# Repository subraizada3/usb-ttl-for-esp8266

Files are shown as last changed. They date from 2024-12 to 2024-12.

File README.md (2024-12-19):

# USB UART TTL for ESP8266

This is a compact CP2102N-based USB Type-C TTL UART breakout board that also includes the DTR and RTS pins needed for button-free programming of the ESP8266.

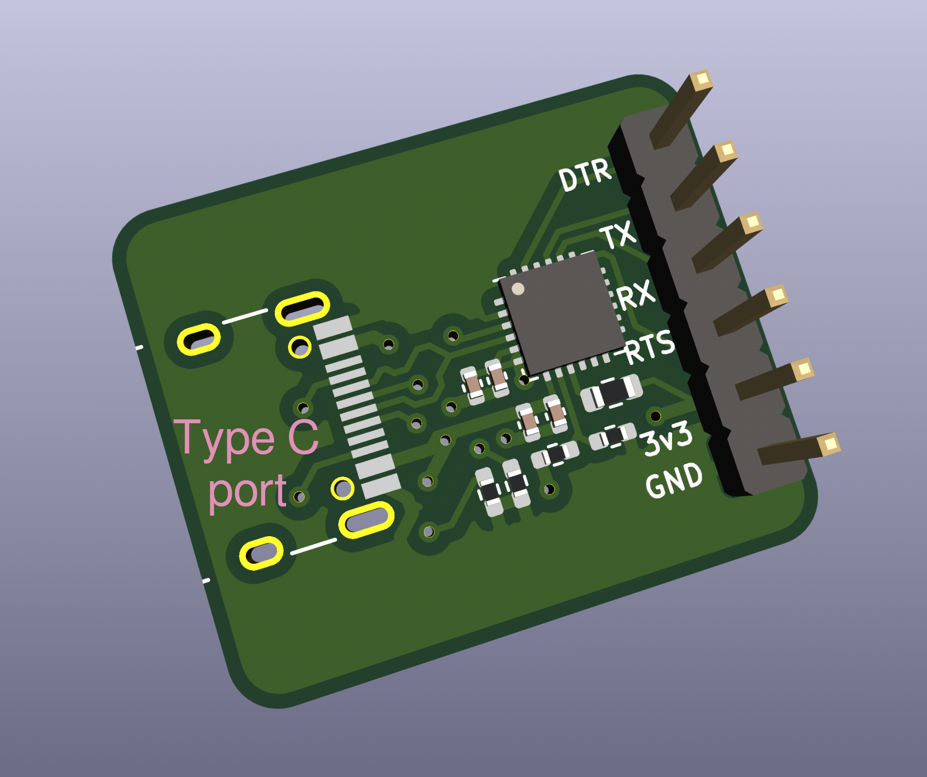
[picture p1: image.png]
image of board


USB TTL UART adapters available on the market have issues:
- The smaller adapters that have a Type C port don't break out the DTR & RTS pins
- The adapters that do break out DTR & RTS pins also break out a bunch of other unneeded pins, and they're large & bulky. They also have a micro-USB port instead of Type C.

This adapter breaks out all pins needed for efficient ESP8266 development while remaining as compact as possible.

This was created in 2021; the market may have more suitable offerings available at this point.

See [bom.xlsx](bom.xlsx) for the list of parts to order from LCSC or for JLCPCB assembly. [pos.xlsx](pos.xlsx) is the part positioning file for JLCPCB assembly.

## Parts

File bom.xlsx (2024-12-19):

Comment | Qty | Designator | Footprint | Name | LCSC Part # | Extended?
CP2102N 24 pin | 1 | U1 | QFN-24_4x4x05P | CP2102N-A02-GQFN24R | C969151 | Yes
USB type C 12 pin | 1 | J1 | TYPE-C-31_L8.94_W7.3 | TYPE-C-31-M-12 | C165948 | Yes
Male header 1x6 | 1 | J2 | Through hole | C37208 | C37208
Resistor 5.1k | 2 | R1,R2 | R0402 | 0402WGF5101TCE | C25905
Resistor 1k | 1 | R3 | R0603 | 0603WAF1001T5E | C21190
Resistor 22k | 1 | R4 | R0402 | 0402WGF2202TCE | C25768
Resistor 47k | 1 | R5 | R0402 | 0402WGF4702TCE | C25792
Capacitor 4.7uF | 2 | C1,C3 | C0402 | CL05A475MP5NRNC | C23733
Capacitor 100nF | 2 | C2,C4 | C0402 | CL05B104KO5NNNC | C1525

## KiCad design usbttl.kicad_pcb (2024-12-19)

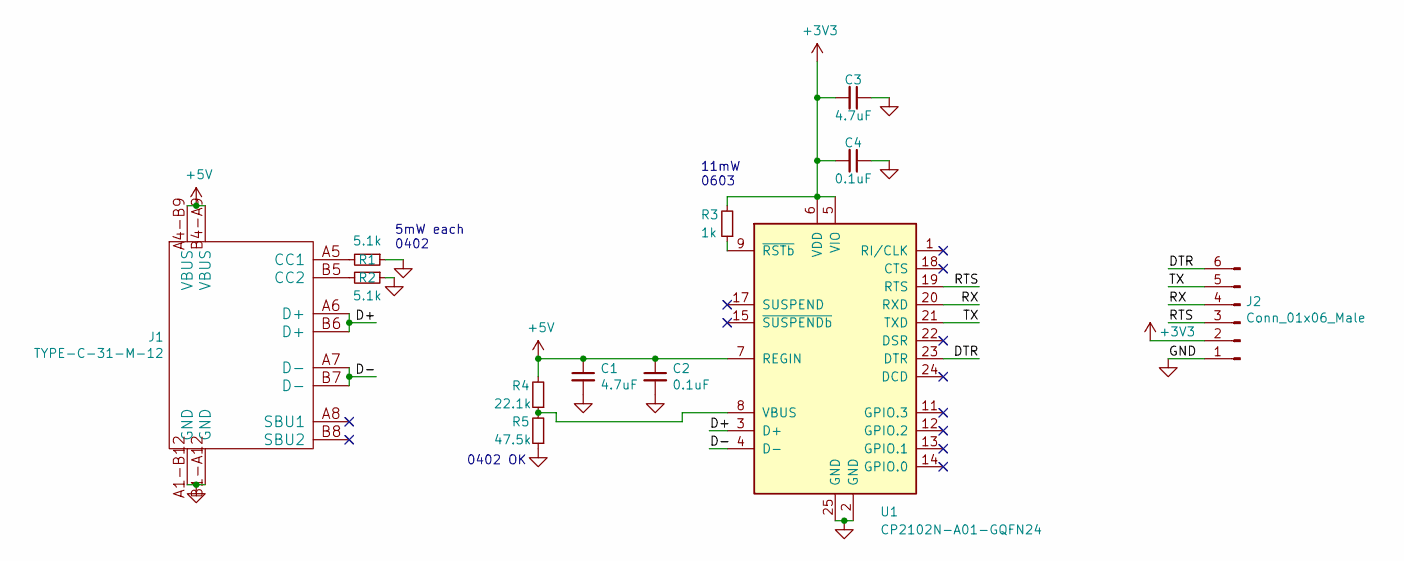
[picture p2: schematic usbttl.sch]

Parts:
C1, C3: 4.7uF; C_0402_1005Metric
C2, C4: 0.1uF; C_0402_1005Metric
J1: TYPE-C-31-M-12
J2: Conn_01x06_Male; PinHeader_1x06_P2.54mm_Vertical
R1, R2: 5.1k; R_0402_1005Metric_Pad0.72x0.64mm_HandSolder
R3: 1k; R_0603_1608Metric
R4: 22.1k; R_0402_1005Metric_Pad0.72x0.64mm_HandSolder
R5: 47.5k; R_0402_1005Metric_Pad0.72x0.64mm_HandSolder
U1: CP2102N-A01-GQFN24; QFN-24-1EP_4x4mm_P0.5mm_EP2.6x2.6mm

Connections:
+3V3: C3.2, C4.2, J2.2, R3.2, U1.5 (VIO), U1.6 (VDD)
+5V: C1.1, C2.1, J1.A4-B9 (VBUS), J1.B4-A9 (VBUS), R4.2, U1.7 (REGIN)
/D+: J1.A6 (D+), J1.B6 (D+), U1.3 (D+)
/D-: J1.A7 (D-), J1.B7 (D-), U1.4 (D-)
/DTR: J2.6, U1.23 (DTR)
/RTS: J2.3, U1.19 (RTS)
/RX: J2.4, U1.20 (RXD)
/TX: J2.5, U1.21 (TXD)
GND: C1.2, C2.2, C3.1, C4.1, J1.A1-B12 (GND), J1.B1-A12 (GND), J2.1, R1.1, R2.1, R5.1, U1.2 (GND), U1.25 (GND)
unnamed: J1.A5 (CC1), R1.2
unnamed: J1.B5 (CC2), R2.2
unnamed: R3.1, U1.9 (~RSTb)
unnamed: R4.1, R5.2, U1.8 (VBUS)

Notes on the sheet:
11mW 0603
5mW each 0402
0402 OK

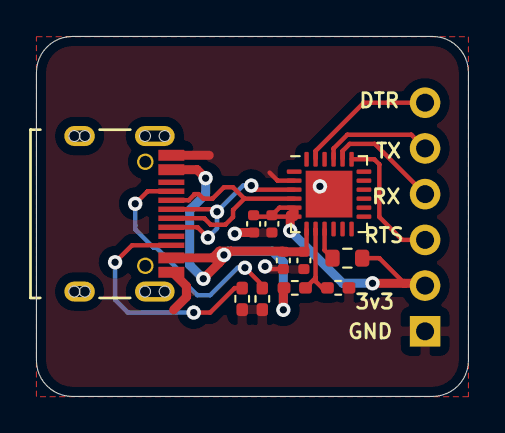
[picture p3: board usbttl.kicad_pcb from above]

Board: 2 copper layers, 24.0 x 20.0 mm, 12 parts (0 on the bottom side), 13 nets.
